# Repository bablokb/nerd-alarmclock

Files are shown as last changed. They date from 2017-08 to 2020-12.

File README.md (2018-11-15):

nerd-alarmclock
===============

A Pi-Zero W based alarm-clock for nerds with many unique functions:

 - wake-up light (using Pimoroni's *Blinkt!*)
 - clock display (using Pimoroni's *Four Letter pHat*)
 - play sounds or internet radio
 - use a chat-bot for configuration

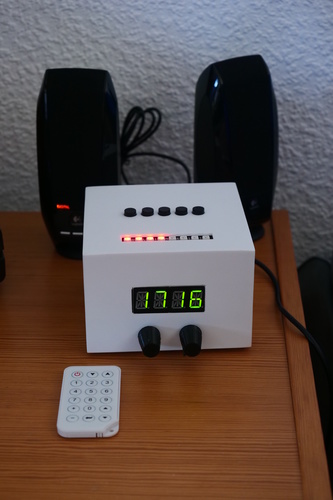
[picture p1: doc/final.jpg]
Alarm-Clock in it's 3D-printed case
After a few prototypes, there is now a nice case: . You can download and modify the design from
[3D-case](https://www.tinkercad.com/things/7gM0KUdlLRA "Nerd Alarmclock Case").
STL-files are also available from the [misc-directory](misc/ "misc directory").

Table of Contents
-----------------

  1. [News and Status](#news "News")
  2. [Installation](#install "Installation")
  3. [Hardware](#hardware "Hardware")
  4. [Prerequisites](#prerequisites "Prerequisites")
  5. [Configuration](#configuration "Configuration")
  6. [Usage](#usage "Usage")
  7. [Hacking](#Hacking "Hacking")

News
----

As always, the software and documentation is work in progress.
A detailed list of functions (current and planned) is available in the
document [Features](doc/features.md "Features"). Nevertheless, once in a
while I will release a stable version.

Available branches:

  - **stable_v?**: stable versions (frozen)
  - **master**: the current stable branch plus fixes
  - **next**: the bleeding-edge development version with new features, but
              possibly unstable

### next / work in progress ###

  - enable update of settings from web-interface (planned)

### stable_v3 / Nov 15, 2018 ###

Besides fixing some minor bugs, this version adds the following features:

  - control the clock using an IR remote
  - use the LED-strip as a lamp
  - add parameter `delay` to all alarms (e.g. to start the sound later than
    the light)
  - add configuration of text-alarms via bot
  - add "lights-off-mode": turn of/on LEDs and display
  - Add a web-interface to be independent from telegram
    (currently read-only, i.e. no update of settings from the web-interface yet)

Note that you should read the section *Upgrade* below if you are upgrading
from a previous version.

### stable_v2 / Dec 08, 2017 ###

Besides fixing some minor bugs, this version adds the following features:

  - add support for internet-radio
    - play radio independently of alarms
    - two encoder-knobs (KY040) for on/off and volume and for switching
      between channels and channel-lists
  - add support for snoozing alarms
  - added a set of overlay-functions initiated by a long press of button-2:
    - restart the clock
    - reboot the system
    - shutdown the system
  - refactored code for future IR remote control suoport

For details, see [Features](doc/features.md "Features").

Note that you should read the section *Upgrade* below if you are upgrading
from stable_v1.

### stable_v1 /  Sept 14, 2017 ###

First productive version. All basic features working.

Prerequisites
-------------

Besides the hardware-modules listed in section [Hardware](#hardware "Hardware")
and the software-environment described in
[Installation](#install "Installation") there are no special prerequisites
with the exception of a telegram ID and your own telegram-bot.
If you don't want to use telegram you either have to configure the alarms
using ssh, or wait for the yet to come web-interface.

Registering with telegram is easy, just download the messenger and follow
the instructions. After that, start a chat with @BotFather and this chatbot
will lead you through the process of defining your own bot.

Hardware
--------

From hardware-side, you need

  - a Pi with internet access (a Pi-Zero-W will do fine)
  - the [LED-strip *Blinkt!* from Pimoroni](https://shop.pimoroni.com/products/blinkt "Blinkt!")
  - the [segment-display *Four Letter pHat*](https://shop.pimoroni.com/products/four-letter-phat "Four-Letter-pHat")
    from the same manufacturer
  - four to five buttons, e.g. a cheap [4-key keypad](doc/keypad.jpg) available
    from ebay or Amazon marketplace.
  - a real-time-clock (DS3231, optional)
  - jumper cable or an extension board
    (e.g. a [Mini Black HAT Hack3r](https://shop.pimoroni.com/products/mini-black-hat-hack3r "Extension board"))
  - two encoder-knobs (KY040) for controlling the internet-radio (optional)

Since you need the GPIOs for both hardware extensions, you cannot just
plug in the LED-strip or the hat on the Pi. You can either
connect the components using
[some jumper cables](doc/assembly.jpg "Assembly"), or you use an extension board.
When using jumper cables, observe the pinout provided by
[https://pinout.xyz](https://pinout.xyz "Pinout"). The pins are also
documented [here](doc/pins.md "Pins").

Installation
------------

As a prerequisite, you need a basic install of Raspbian Jessie-Lite or
Stretch-Lite, but note that the latter has problems with the initial
configuration of IR-remotes (an IR configured under Jessie will work fine
with Stretch though).

Use the following commands to install the software:

    git clone https://github.com/bablokb/nerd-alarmclock.git
    cd nerd-alarmclock
    sudo tools/install
    cd ..
    git clone https://github.com/bablokb/gpio-poll-service.git
    cd gpio-poll-service
    sudo tools/install

This will pull-in all dependencies, install the software, create technical
users and do a basic configuration of the system. Since the install command
changes the file `/boot/config.txt`, you need a reboot to activate the changes.

Note that the installation of the gpio-poll-service will ask you to configure
the service (file `/etc/gpio-poll.conf`), but this project already
provides a suitable configuration file.

Upgrade
-------

Before uprading an existing system, you should stop the relevant system
services:

    sudo systemctl stop nerd-alarmclock.service
    sudo systemctl stop gpio-poll.service

Then run a normal install like documented above. After installation, you
should update you existing `/etc/nerd-alarmclock.conf` from the file
`/etc/nerd-alarmclock.conf.nerd-alarmclock` and the file `/etc/gpio-poll.conf`
from the file `/etc/gpio-poll.conf.nerd-alarmclock`.

Configuration
-------------

### System services ###

Edit the file `/etc/nerd-alarmclock.conf` to configure the systemd-service
running the clock. In this file, you at least have to edit the section
`[BOT]` and enter your own user-id and the id of your bot. The latter is
provided by *BotFather*. To query your own id, edit the python-script
`tools/simplebot.py`, start it and exchange some messages with the bot.
The script will print all messages and you will find your own id in the
messages (extract the "from-id").

You should also make sure that the GPIOs configured in `/etc/gpio-poll.conf`
match the GPIOs in the section `[GPIO]` of `/etc/nerd-alarmclock.conf`.

### Bot configuration ###

The bot of the alarmclock uses a predefined set of commands. You should
register the following commands for your bot with *BotFather*:

| Command | Description |
| ---|---|
| `/alarm` | Configure alarms |
| `/restart` | Restart the clock |
| `/reboot`  | Reboot the system |
| `/shutdown`| Shutdown the system |
| `/start` | Start a dialog with the bot |
| `/help` | Provide help |
| `/settings`| Show settings |

This is not strictly necessary, but it greatly simplifies interaction with
the bot.

### IR remote ###

The alarm clock can also be controlled using an IR remote control. First, you
have to install IR support (lirc) and configure your remote. There are
various tutorials on the net, please make sure you follow a version for
the base operating system (configuration of lirc has changed in Stretch
compared to Jessie). After configuration, you should have a lirc-configuration
file which maps IR-pulses to (lirc-) keynames.

Once you have the lirc keynames, you must map the keys using these keynames
to logical functions of the nerd-alarmclock. This is done in the section
`[LIRC]` of `/etc/nerd-alarmclock.conf`. The installation provides a sample
configuration, depending on your remote, you will want to change the
mapping or add additional functions.

A special function is called `LONG` (in the sample mapping assigned to `KEY_0`).
Pressing this key will simulate a long-press for the following key. E.g.
if you press `KEY_0` and then `KEY_1`, this will emulate a long press
of `BTN1` (which in turns activates the first set of overloaded functions for
all keys). Since most remotes have enough keys, this feature is not
really necessary when using a remote control.

### Audio ###

The install script will add a file `/etc/asound.conf` which is suitable for
USB-audio. If you use the pHat-DAC, you should move the file
`/etc/asound.conf.pHatDAC` to `/etc/asound.conf`. Note that the pHat-DAC
uses GPIO19, so you have to reconfigure the default setup of the pins
(edit the files `/etc/nerd-alarmclock.conf`, `/usr/local/sbin/nerd-gpios.sh`
and `/etc/gpio-poll.conf` and reassign the pin for the encoder-knob).

If you want to use Bluetooth-audio, you should head over to the project
[pi-btaudio](https://github.com/bablokb/pi-btaudio "pi-btaudio") and follow
the instructions.

### Adding sounds ###

To play music or sounds during an alarm, you have to add the files
to the directory `/var/lib/nerd-alarmclock/sounds`. The nerd-alarmclock uses
the program `mpg123` to play the files, so all formats supported by mpg123
should be fine. If you want to play an internet-radio station, add the url
to a file with the extension `m3u` (playlist). Note that mpg123 does not
support nested playlists.

### Adding Radio channel-list ###

Since version v2, the nerd-alarmclock supports playing internet-radio.
The distribution supplies some sample channel-lists in the directory
`/var/lib/nerd-alarmclock/channels`. Add your own lists using the
format in the samples.

Pressing one of the encoder-knobs will cycle through the channel lists,
while turning the knob will cycle through the channels of a given list.
The display will show the name of the channel list after a change for a
few seconds. The same holds true for changing channels.

### Manual configuration ###

Program defaults are in the file `/var/lib/nerd-alarmclock/defaults.json`.
You should not edit this file directly (unless you know what you are
doing). After first run, the settings are saved in
`/var/lib/nerd-alarmclock/settings.json`. You can edit this file
manually, but you should make sure the clock-service is stopped before
doing so (it will be otherwise overwritten).

There are still some settings which you typically only change very
seldomly and these settings are not exposed by the config-interface of the
bot, so you have to change the manually:

  - **day.start**: start of day-mode (e.g. brightness depends on this)
  - **day.end**:   end   of day-mode (e.g. brightness depends on this)
  - **lamp.rgb**:  RGB-values of LEDs in lamp-mode
  - **lamp.brightness**:  brightness of LEDs in lamp-mode
  - some special options to tweak the alarms

Usage
-----

After initial configuration as explained above, restart the system and then
it should just run. Use the bot to configure alarms and the buttons to
enable or disable the alarms. See [keyboard usage](doc/keyboard.md
"Keyboard Usage") for details about the behaviour of the buttons.

The two encoder-knobs have builtin switches. One encoder-knob controls
the radio (switch: on/off, dial: volume), the other knob controls the
channels (switch: cycle channel-lists, dial: choose channel).

Hacking
-------

If you want to change the code and adapt it for your needs, you need some
python know-how and you have to understand the structure of the program.
For details read the [hacking-guide](doc/hacking.md "Hacking-Guide").

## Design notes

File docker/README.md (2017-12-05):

# Usage

To run the docker container you need a image for your raspberry pi that supports
docker. You can use a default image and install docker yourself or you can use
an image that already supports docker. The image
[hypriot](https://blog.hypriot.com/getting-started-with-docker-on-your-arm-device/)
for example.

If the image is working, you have to run this before launching the docker container:
```
sudo chown 1000:1000 /dev/gpiomem
```

This will make `/dev/gpiomem` accessible from within the container which can be started with:

```
docker run -it -v nerdc_home:/var/nerdc_home --device /dev/snd --device /dev/gpiomem -t benjaminfuchs/rpi-nerd-alarmclock /bin/bash
```

This will start an docker container that already has all set up for the
nerd-alarmclock. The settings should be store in /var/nerdc_home. The
command automatically creates a 'nerdc_home' docker volume, that will
survive container stop/restart/deletion. The cointainer has a script called
`start-nerdc.sh` to manually start the nerd-alarmclock. If you manually created your
`settings.json` you can use following command to only start the container with
the saved settings:

```
docker run -v nerdc_home:/var/nerdc_home --device /dev/snd --device /dev/gpiomem -t benjaminfuchs/rpi-nerd-alarmclock
```

Avoid using a bind mount from a folder on host into `/var/nerdc_home`, as this
might result in file permission issue. If you _really_ need to bind mount
jenkins_home, ensure that directory on host is accessible by the jenkins user in
container (jenkins user - uid 1000) or use `-u some_other_user` parameter with
`docker run`.

For more info check Docker docs section on [Managing data in
containers](https://docs.docker.com/engine/tutorials/dockervolumes/)

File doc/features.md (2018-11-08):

Features
========

Implemented
-----------

  - Display the current time on the display
  - Show the day of the month on the LED-strip (using colors and number of LEDs)
  - Use the LED-strip as a lamp (**new**)
  - Play internet radio (**since v2**)
  - Update time automatically from RTC and/or internet time-servers
  - Brightness of the display and the LED strip is configurable
    (off and four levels)
  - Brightness independently configurable for "day" and for "night" with
    automatic switching
  - If brightness is zero pushing the "snooze"-button will show the display
    for two seconds (the 4-letter-pHat is still too bright at night, even at
    it's dimmest setting). (**since v2**)
  - turn off/on display and LEDs (with the option to turn the lights on
    after an alarm) (**new**)
  - Support four alarms
  - Every alarm is configurable
    * time
    * day(s) of the week
    * duration
    * delay for light, dispay and sound (e.g. sound will start 2 minutes after
      the alarm starts) (**new**)
    * snooze-time (**since v2**)
    * type of light-alarm to show
    * type of display-alarm to show (e.g. some running text)
    * song/playlist to play (playlists also support internet-radio)
    * volume
    * fade-in time (from 0 to requested volume)
  - basic operation using four buttons
    * turn alarm on or off or stop a running alarm
    * cycle through display brightness
    * cycle through LED brightness
  - Control internet radio using two encoder-knobs (**since v2**)
    * on/off and set volume
    * cycle through channel-lists and cycle through stations (within list)
  - snooze a running alarm (i.e. stop it and restart it after a given delay).
    Can be implemented with a fifth  button or by redefining an existing button.
    (**since v2**)
  - use an IR-remote to control the alarm-clock and radio (**new**)
  - detailed configuration using a telegram chat-bot
    * configure alarms
    * restart the clock
    * reboot or shutdown the system
  - Restart/Reboot/Shutdown available from push-button (**since v2**)
  - Provides a web-interface (currently read-only) (**new**)

Planned
-------

  - enable configuration-updates from the web-interface
  - show metadata (ICY-tags) on the display

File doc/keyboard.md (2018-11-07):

Keyboard Control
================

The number of buttons you can use depends on your physical setup. The default
setup uses four standard buttons and a fifth button for special actions, e.g.
for snoozing an alarm (see below). If you don't have a fifth button, you
can redefine button-4 to take over these functions (but you loose an alarm).

Each of the buttons supports a short-press and a long-press. The default
function mapped to the short-press is the control of the alarm. A long
press will do something different, e.g. map a different set of functions
to all keys. 

Default Functions
-----------------

Each of the buttons toggles the state of respective alarm, e.g. button `1`
controls `alarm1`:

| Button | short-press function | long-press function |
|---|---|---|
| `1` | toggle state of alarm 1  | load overloaded functions (set 1) |
| `2` | toggle state of alarm 2  | load overloaded functions (set 2) |
| `3` | toggle state of alarm 3  | |
| `4` | toggle state of alarm 4  | toggle lights-off mode |
| `SNZ`  | snooze / show display | toggle lamp |

State transistions for alarms:

| old state | new state |
|---|---|
| disabled  | enabled |
| enabled | disabled  |
| ringing | enabled |
| snooze | enabled |

Overloaded Functions (Set 1)
----------------------------

A long press of button `1` activates this set of overloaded functions.
A second long press will toggle back to the default functions.

| Button | short-press function |
|---|---|
| `1` | cycle LED brightness |
| `2` | cycle display brightness |
| `3` | cycle LED modes |
| `4` | cycle display modes (not implemented yet) |

Overloaded Functions (Set 2)
----------------------------

A long press of button `2` activates this set of overloaded functions.
A second long press will toggle back to the default functions.

| Button | short-press function |
|---|---|
| `1` | restart the clock |
| `2` | reboot the system |
| `3` | shutdown the system |
| `4` | |

Snooze Button
-------------

Currently, the snooze-button operates as follows:

  - if no alarm is ringing and if the brightness of the display
    is currently turned off (e.g. during the night), pressing the button
    will show the display for two seconds
  - if an alarm is ringing, pressing the button will snooze the alarm
    for the configured snooze-time (turn it off and start it later again)
  - a long press of the button will turn on (or off) all LEDs thus using
    the LED-strip as a lamp

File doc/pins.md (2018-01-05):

GPIO-Pins used
==============

|Use |Desc. | Odd  | Even | Desc. | Use |
|---|---|-----:|:-----|---|---|
|RTC |3.3V | 1  |  2 | 5V | 4LpHat, Blinkt |
|RTC, 4LpHat |SDA | 3  |  4 | 5V | |
|RTC, 4LpHat |SCL | 5  |  6 | GND | RTC, 4LpHat, Blinkt |
|Btn2 |GPIO04 | 7  |  8 | | |
|Keyboard |GND | 9  | 10 | | |
|Btn1 |GPIO17 |  11  | 12 | | |
|Btn4 |GPIO27 |  13  | 14 | GND | |
|Btn3 |GPIO22 |  15  | 16 | GPIO23 | Blinkt |
|4LpHat |3.3V |  17  | 18 | GPIO24 | Blinkt |
| |SPI_MOSI |  19  | 20 | GND | |
| |SPI_MISO |  21  | 22 | GPIO25 | SNZ |
| |SPI_CLK  |  23  | 24 | SPI_CE0_N | |
| |GND |  25  | 26 | SPI_CE1_N | |
| |ID_SD |  27  | 28 | ID_SC | |
|EK1_CLK |GPIO05 |  29  | 30 | GND | |
|EK1_DT |GPIO06 |  31  | 32 | GPIO12 | EK1_SW |
|EK2_CLK |GPIO13 |  33  | 34 | GND | |
|EK2_DT |GPIO19 |  35  | 36 | GPIO16 | EK2_SW |
|IR |GPIO26 |  37  | 38 | GPIO20 | |
| |GND |  39  | 40 | GPIO22 | |

Note that EK2_DT conflicts with the pHat-DAC. If you want to use both
the encoder-knob and the pHat-DAC, you have to connect the data-pin
of EK2 to a different pin and changes various files (see the README.md
for details).

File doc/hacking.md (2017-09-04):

Hacking-Guide
=============

Architecture
------------

The firmware for the alarmclock is implemented in python. The main program
is the script `/usr/local/sbin/nerd-alarmclock.py`, which is started by
the systemd-service defined in `/etc/systemd/system/nerd-alarmclock.service`.

The main script does not contain much logic. It mainly creates and loads
various object taking care of the hardware. All classes are submodules
of the `nclock`-module. During installation, the code is copied to
`/usr/local/lib/python2.7/site-packages/nclock`.

Logically, the software follows the [MVC paradigm](./nerdc-objects.png).
The model is implemented in the class `Settings`. The `LedController` and
`DisplayController` are views, and the `KeyboardThread` and `BotThread`
are the controllers.

Objects don't call methods directly, they only change attributes in
the `Settings`. They also register callbacks for attribut-changes
there and are called when the registered attribute changes.

Implementing new Hardware
-------------------------

As an example, we will walk through the implementation of a new hardware
component, which controlls a wall-plug. For this component we will need
a controller that acts as a *alarm-provider* (since we want to turn on
the plug on an alarm event).

So you need to implement and change the following code:

  1. Create a class `PlugController` in
     `/usr/local/lib/python2.7/site-packages/nclock/PlugController.py`
  2. Import the sub-module in
     `/usr/local/lib/python2.7/site-packages/nclock/__init__.py`
  3. Instantiate the `PlugController` in
     `/usr/local/sbin/nerd-alarmclock.py`

To act as an alarm-provider, the class must implement and register a method
which will provide an alarm-thread. You are free to choose a suitable name
for this method, but by convention it is named `get_alarm`. You can use an
existing controller (e.g. `SoundController`) as a template.

The `get_alarm`-method will return either `None` (no alarm configured), or
a thread. The thread in this case would just turn on the wall-plug.

Since this is a new component, there is no UI to configure the plug-alarm.
You either have to edit the settings.json file manually, or you have to
extend the `BotThread` or `WebThread`.

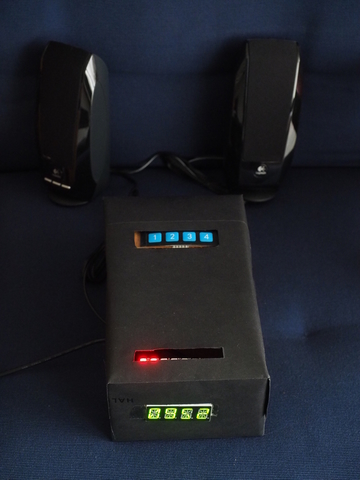
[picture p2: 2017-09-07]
doc/prototype.jpg

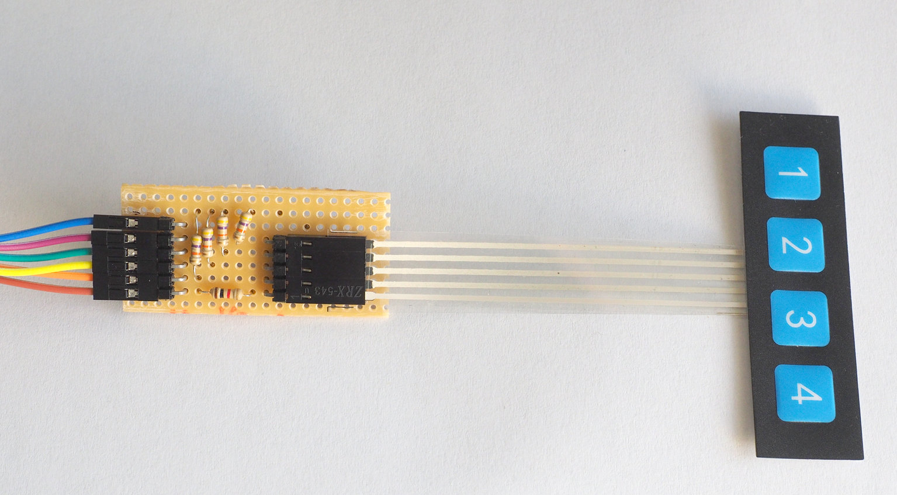
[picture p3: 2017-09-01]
doc/keypad.jpg

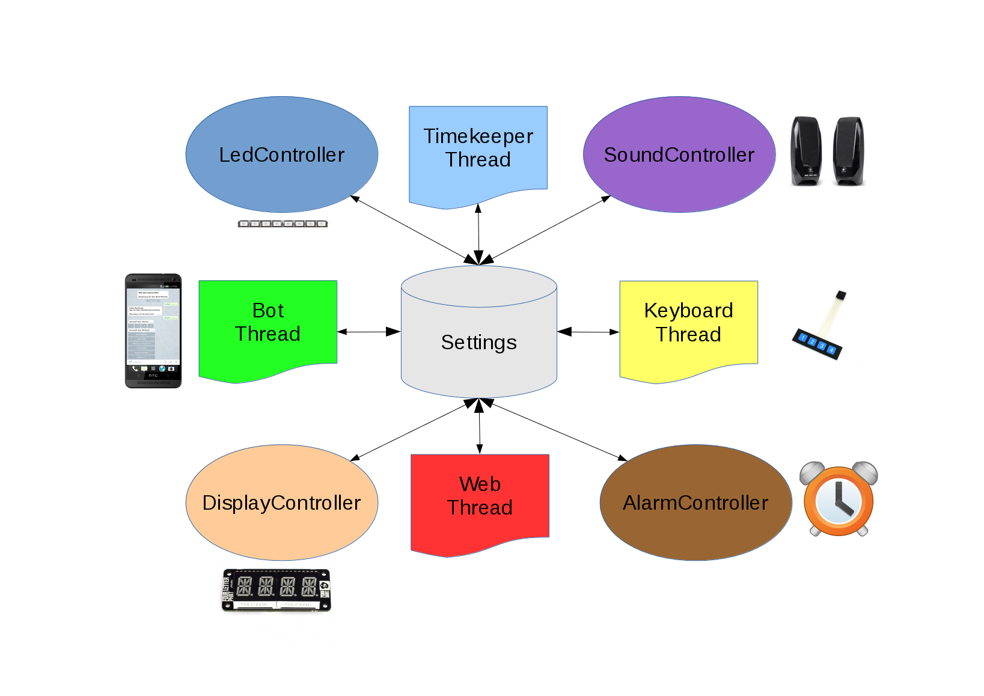
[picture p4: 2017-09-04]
doc/nerdc-objects.png

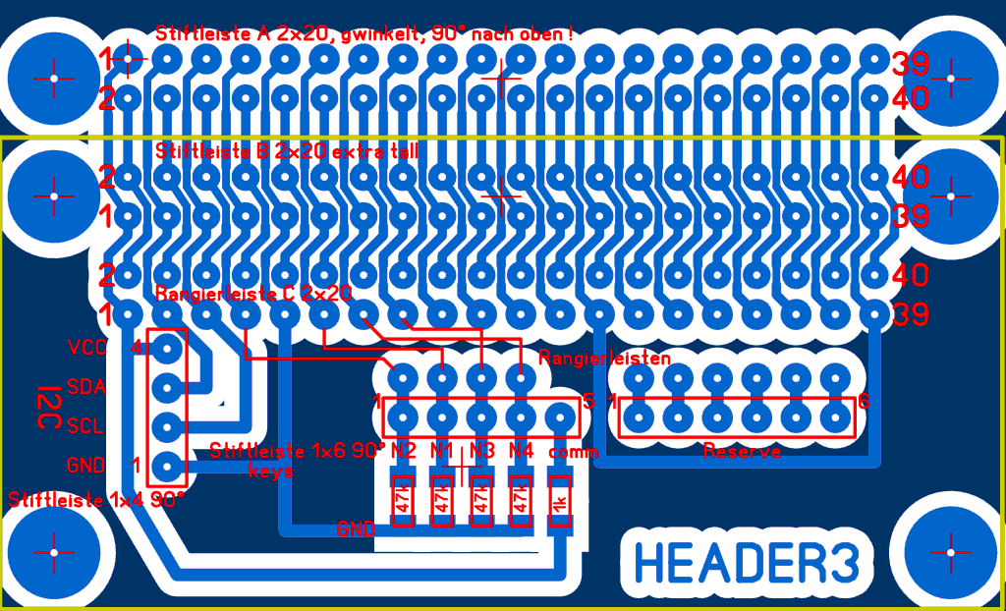
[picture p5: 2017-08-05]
doc/circuit.gif

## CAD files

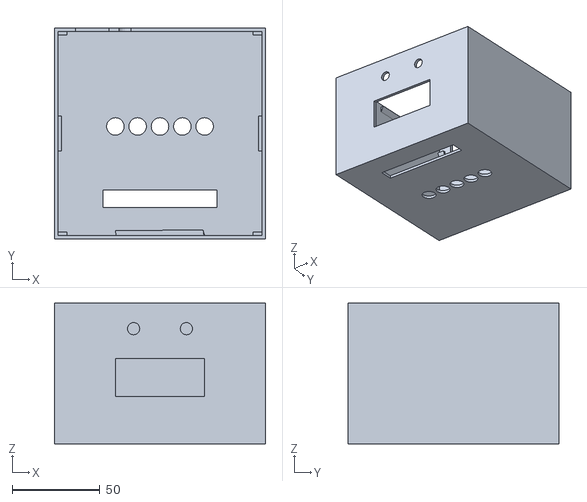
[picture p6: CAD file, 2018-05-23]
misc/Main Body.stl
120.0 x 120.0 x 80.0

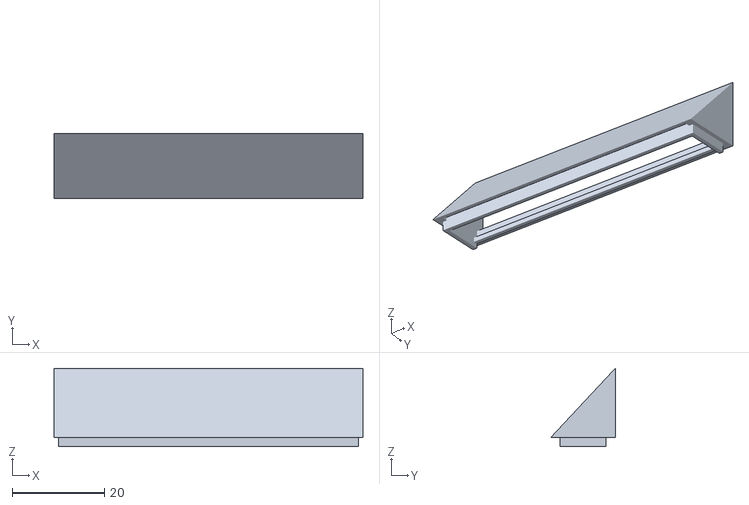
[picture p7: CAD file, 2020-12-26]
misc/Diffusor.stl
67.0 x 14.0 x 17.0

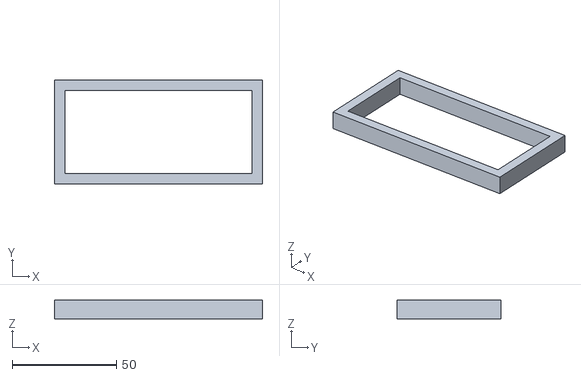
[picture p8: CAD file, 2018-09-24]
misc/Button Support.stl
100.0 x 50.0 x 9.00

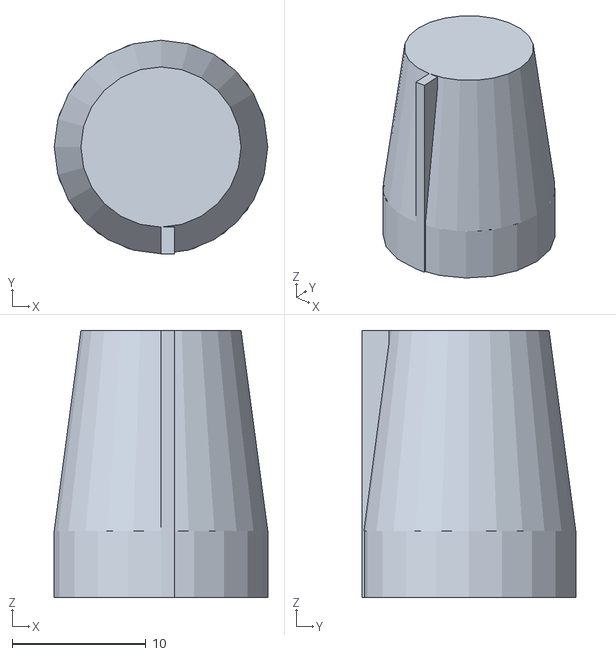
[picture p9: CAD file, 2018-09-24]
misc/Encoder Knob.stl
16.0 x 16.0 x 20.0

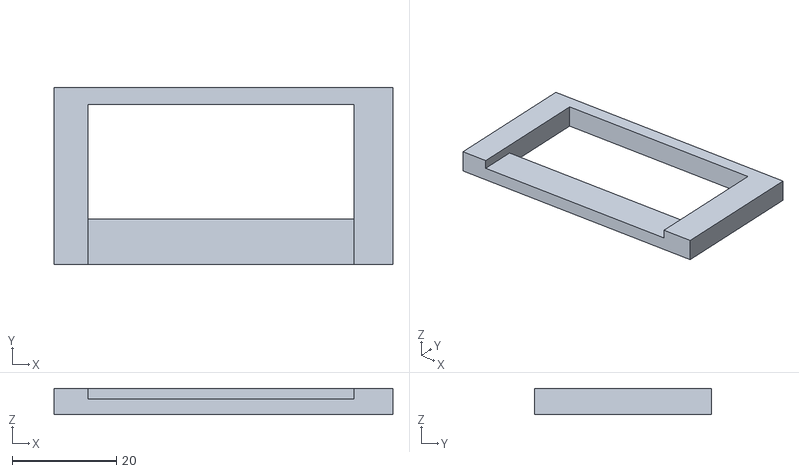
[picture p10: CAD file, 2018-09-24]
misc/Display Support.stl
65.0 x 34.0 x 5.00

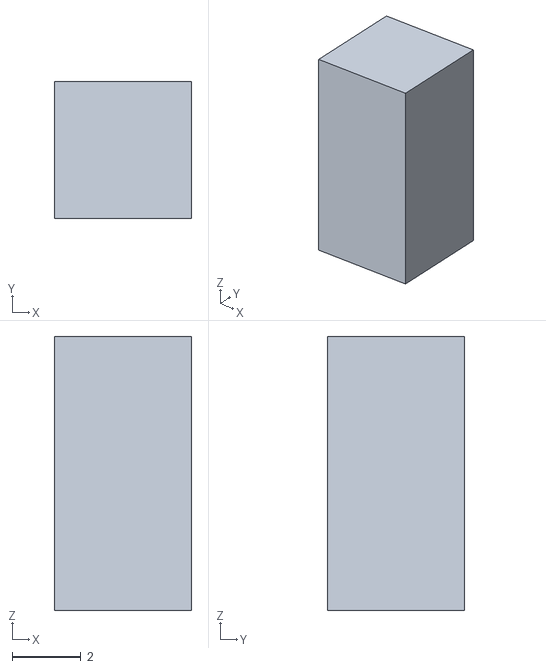
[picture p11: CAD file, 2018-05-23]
misc/Base Support.stl
4.00 x 4.00 x 8.00

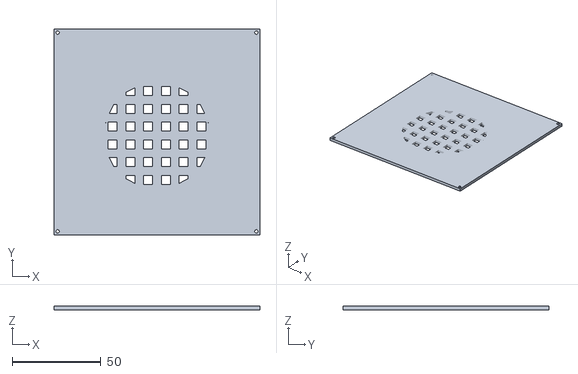
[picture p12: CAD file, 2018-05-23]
misc/Base.stl
116.0 x 116.0 x 2.00

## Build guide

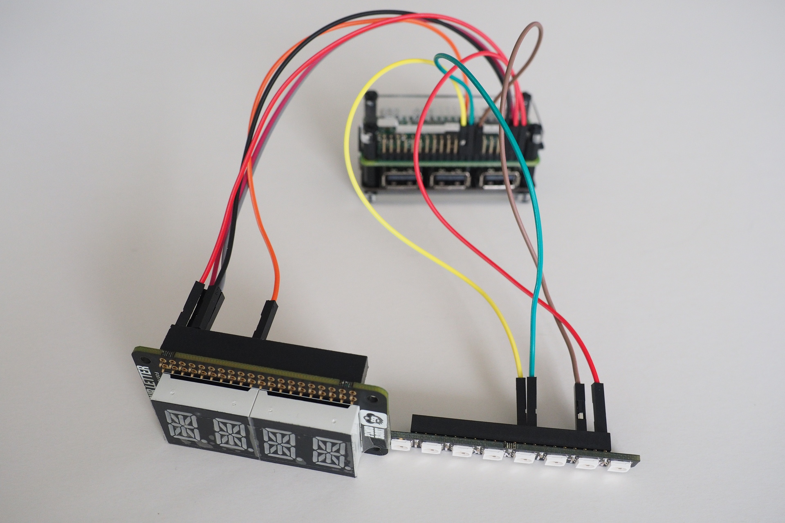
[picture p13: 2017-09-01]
doc/assembly.jpg

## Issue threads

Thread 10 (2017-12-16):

BotThread: support individual duration for LED-alarms and sound-alarms

bablokb, 2017-12-16:
Currently the bot-interface configures only one duration for both types of alarms.

bablokb, 2017-12-24:
Implemented with  commit d52c2fadabd1a4a5e3254921ef0eb05a4d576a75

Closed 2017-12-24.

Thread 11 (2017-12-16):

Add attribute "delay" to alarms and bot-interface

bablokb, 2017-12-16:
Currently all alarm-types (LED, sound, display) start at the the given alarm time. Adding a delay-attribute would allow e.g. the sound to start a given delay after the LED-alarm.

- [x] add delay=0 parameter to all alarms
- [x] support delay parameter in BotThread

bablokb, 2018-01-22:
Completed

Closed 2018-01-22.

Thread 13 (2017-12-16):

Alarm fails if radio is configured and no internet is available

bablokb, 2017-12-16:
Check behavior of mpg123 when internet access is not possible. If it fails and it is possible to catch the failure, use a fallback alarm. If not, check internet access before starting the alarm and switch to a fallback alarm.

Fallback-alarm: use first available mp3/wav??

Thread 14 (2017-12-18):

Pin conflict with pHat DAC

benjaminfuchs, 2017-12-18:
Hi,
I want to use the nerd-alarmclock on my Pi Zero with the pHat DAC.
I needed to change the `/etc/asound.conf`, that was okay.
But it seems the GPIOs of the EncoderKnobThread are in conflict to the pHat DAC.
Here the PIN usage of it:
https://pinout.xyz/pinout/phat_dac
When I just run the nerd-alarmclock without the EncoderKnobThread it works.
I guess its `EK2_DT:  19` ... https://github.com/bablokb/nerd-alarmclock/blob/6689ec7f437de7fed93d24522bfe807c2af99f5a/files/etc/nerd-alarmclock.conf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 ... that makes the conflict since if I change that one to any other pin the sound works again with EncoderKnobThread active.
Is it possible to use another GPIO pin for that or do I need to make a configuration to choose what to use PIN 19 for (sound/knob)?

bablokb, 2017-12-19:
Hi,
three things to do:
  - change the pin-number for EK2_DT in nerd-alarmclock.conf. Available/used pins are in doc/pins.md
  - update /etc/gpio-poll.conf (add your replacement pin, remove pin 19)
  - update /usr/local/sbin/nerd-gpios.sh (ditto)

Three places is not very nice, we could probably merge nerd-gpios.sh into the startup code of nerd-alarmclock.py to get rid of at least one place.

benjaminfuchs, 2017-12-19:
Should I change this for the whole project and properly mention pHat DAC to READMEs and PIN docu?

benjaminfuchs, 2017-12-19:
I dump the `asound.conf` here so it is somewhere safe:
```
pcm.!default {
  type hw
  card 0
}
ctl.!default {
  type hw
  card 0
}
pcm.hifiberry {
    type softvol
    slave.pcm "plughw:0"
    control.name "Master"
    control.card 0
}
pcm.!default {
    type             plug
    slave.pcm       "hifiberry"
}
```

bablokb, 2017-12-21:
Hi,
I suggest that you add a asound.conf.pHatDAC and mention this in the README.

bablokb, 2018-01-05:
Added /etc/asound.conf.pHatDAC with commit bc3949b50b6495d4d0b8a365aad59fe2582b1ba5. Updated README.md with commit a75c8eb5b46b5168e071ae28e0721dc7ac11742d.

Closed 2018-01-05.

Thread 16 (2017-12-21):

RTC

Wuchta, 2017-12-21:
Hi I like the project. But I don't understand how the RTC is connected.
According to the pins it is connected to 1,3,5 and Ground. but 1,3,5 is already occupied by the 4LpHat. Thanks for your work.

bablokb, 2017-12-22:
You need an expansion board to physically attach both the RTC and the 4LpHat. Both use the I2C bus (pins 3 and 5), but as long as the addresses don't overlap, this is no problem.

Closed 2017-12-22.

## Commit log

2017-07-16 start threads using map() after all threads were created
2017-07-17 log messages instead of printing
2017-07-20 initialize LEDs on start
2017-07-21 implemented default functions for buttons
2017-07-21 fixed pin-number ('4' instead of '04')
2017-07-23 implement button-4 toggle function
2017-07-23 added stub functions for overlay-functions of buttons
2017-07-28 keep track of date in addition to time
2017-07-28 return sample thread for get_alarm
2017-07-31 added wiringpi to package-list
2017-07-31 reset LEDs to standard after alarm
2017-08-14 changed role of button 1 and button 4
2017-08-14 updated to current situation
2017-08-22 join on fire-alarm-thread if alarm is stopped because of a new alarm
2017-08-29 bugfix joining terminating alarm-thread
2017-09-05 Fixes missing bracket
2017-09-07 added link to prototype-image
2017-09-19 removed clock and data pins of encoder-knobs
2017-09-19 save current brightness in settings
2017-09-19 handle changes in current brightness
2017-09-19 added new buttons
2017-09-20 dynamically read defined buttons from configuration
2017-09-21 configure ConfigParser to preserve case
2017-09-24 configure restart,reboot,shutdown for button-2 overlay-functions
2017-09-24 document new button behaviour
2017-09-24 document snooze-button
2017-10-05 map functions to encoder-knob switches
2017-10-11 import EncoderKnobThread
2017-10-11 configure and start EncoderKnobThreads
2017-11-04 made polling interruptable
2017-11-07 add special configuration for encoder-knob pins
2017-11-09 snooze-button displays radio-channel if radio is on
2017-11-09 added options to select 'no alarm' for LED and/or sound
2017-11-09 added options to select current radio-station for alarm
2017-11-18 prevent pip from printing errors because of a terminated pipe
2017-12-05 play_sound(): play current radio station if name=='_radio'
2017-12-08 bugfix: encoder-knob switch needs pullup
2017-12-10 Show current time and fix start script.
2017-12-23 support individual durations for LED and sound
2017-12-23 Making WebThreads print less frequent.
2018-01-16 on_list(): bugfix - permanently save current list to settings
2018-01-16 added callbacks for setting delays for sound and leds
2018-01-21 refactor code to support different led-modes
2018-01-21 added settings for led.lamp.xxx
2018-01-22 added on_mode() as led.mode listener
2018-02-19 add mapping LED_MODE: KEY_7
2018-02-19 updated documentation for button3, overlay mode
2018-02-27 save list of led-modes in settings
2018-02-28 fix values of led.mode/display.mode in old installations
2018-05-23 replaced with individual files per part
    [Nerdclock Housing.stl]
2018-09-24 updated version of housing
    [Button Support.stl, Display Support.stl, Encoder Knob.stl]
2018-11-05 link to new image and to source of case
2018-11-08 handle_snz(): fix case lights_off==True
2018-12-15 add function for BTN4-long
    [Buttons-Cheatsheet.ods]
2023-03-07 updated for new button-bar
